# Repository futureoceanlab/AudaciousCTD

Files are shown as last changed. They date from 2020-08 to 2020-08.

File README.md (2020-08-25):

# AudaciousCTD

To understand any phenomenon about the ocean, we need to understand its basic
physical properties. Conductivity, tempreature and pressure are  
common data to be collected to estimate the local salinity of seawater at
certain depths. They are measured by using a sensor referred to as a 
conductivity, temperature and depth (CTD) sensor. It turns out that the existing
technologies are extremely costly due to their precision and depth ratings 
(a list of quates from various companies are available in 
**Markeg_Survey.xlsx**). For some scientific studies, the precision and depth 
rating specifications from these manufacturers are important. However, 
their high cost prevent us from understanding beyond local phenomenon in 
the ocean. 

Ocean is dynamic from molecular to global physical scales. Therefore, it is not
sufficient to operate with a few great CTDs. If their cost of a CTD could be 
lowered, we could have a more detailed understanding of the ocean. Furthermore,
the entry barrier for people to help study the ocean would be lowered 
significantly. We hope to acheive that via Audacious CTD project.

## Software

This was the last version of the MCU code used for the first iteration of the
Audacious CTD. It has not been maintained since June 2019.

The MCU used in this iteration was a STM32F303. 

The role of the MCU is very simple. Every given period, it will sample
the conductivity, temperature and pressure data from its sensors. Then, it will
save them to the flash memory. 

To edit the code, we recommend the use of STM32 Cube IDE. To program
the MCU, we recommend the use of STM32CubeProgrammer. This software also
enables the user to directly import the data that have been written to the 
flash drive. We took this approach in the first iteration.

## Circuit
The latest version of the circuit has been added to this repository. There
are two separte parts. One part has an MCU and its peripherals, and another
part has sensor-related components. The MCU component was housed inside, and
the sensor component was potted in the endcap to expose the sensors to the
seawater. 

At the point of fabrication, we thought having two separate board layouts (one 
for inside the housing and another for exposed circuit with sensors) on one 
board would save cost. However, it only caused confusion on the manufacturing 
company, and we would highly advise simply making two separte boards.

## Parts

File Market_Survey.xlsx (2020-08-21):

Supplier | Item | Conductivity (mS/cm) |  |  | Temperature (°C) |  |  | Depth (m) |  |  | Price | Link
 |  | Range | Accuracy | Resolution | Range | Accuracy | Resolution | Range | Accuracy | Resolution
STAR:ODDI | DST CTD Online | 13 to 63 | ±2 | 0.02 | -1 to 40 | ±0.1 | 0.032 |  | ±0.6% | 0.03% | $2980.00 | https://www.star-oddi.com/products/submersible-water-sensors/conductivity-salinity-sensor
 |  | 13 to 50 | ±1.5 | 0.01 | -1 to 41 | ±0.1 | 0.032 |  | ±0.6% | 100.03%
 |  | 3 to 37 | ±1.5 | 0.01 | -1 to 42 | ±0.1 | 0.032 |  | ±0.6% | 200.03%
 |  | 0.3 to 5 | ±0.3 | 0.002 | -1 to 43 | ±0.1 | 0.032 |  | ±0.6% | 300.03%
AML | Base-X | 0 to 90 | ±0.01 | ±0.003 | -5 to 45 | ±0.005 | ±0.003 | 500 | ±0.05% FS | 0.03%FS | $7225.00 | https://amloceanographic.com/product/base-x/#sound-velocity
 | Minos-X | 0 to 90 | ±0.01 | ±0.003 | -5 to 45 | ±0.005 | ±0.003 | 1000 | ±0.05% FS | 0.03%FS | $10085.00
Teledyne Marine | CT-EK Digital | 0 to 70 | ±0.1 | 0.0001 | -2 to 35 | ±0.05 | 0.0001 | 500 |  |  |  | http://www.teledynemarine.com/citadel-ct-ek-digital?ProductLineID=31
 | CT-EK Analog | 0 to 70 | ±0.01 | - | -2 to 35 | ±0.05 | - | 500 |  |  |  | http://www.teledynemarine.com/citadel-ctd-ek-analog?ProductLineID=31
 | CTD-ES | 0 to 70 | ±0.003 | 0.001 | -2 to 32 | ±0.002 | 0.0001 | 500 |  |  |  | http://www.teledynemarine.com/citadel-ctd-es?ProductLineID=31
OGI (Valeport) | miniCTD | 0 to 80 | ±0.01 | 0.001 | -5 to 35 | ±0.01 | 0.001 |  |  |  |  | http://www.valeport.co.uk/Portals/0/Docs/Datasheets/Valeport-miniCT.pdf
Idronaut | OS307 | 0 to 90 | ±0.003 | 0.0003 | -5 to 40 | ±0.003 | 0.001 | 0 to 1000 | 0.01% | 0.001% | EUR 4800 | https://www.idronaut.it/sensors/os307-oem-modules/#1560333614808-f7202d5a-61f3
 |  | 0 to 90 | ±0.003 | 0.0003 | -5 to 40 | ±0.003 | 0.001 | No Depth Sensor |  |  | EUR 4000
OpenCTD |  | 0.005 to 200 | ±2% | 0.001 | -55 to 125 | ±0.5 |  | 300 |  |  | $400.00 | https://github.com/OceanographyforEveryone/OpenCTD
OTT HydroMat | OTT CTD Sensor | 0.1 to 100 | ±1.5% | 0.01 | -25 to 70 | ±0.1 | 0.01 | 100 |  |  | - | https://www.ott.com/products/water-level-1/ott-ctd-sensor-37/
 | HL4 | 0 to 100 | ±0.5%+0.001 | 0.001 |  |  |  |  |  |  |  | https://www.ott.com/products/water-quality-2/hydrolab-hl4-multiparameter-sonde-54/
MeterGroup | ES-2 | 0 to 120 | ±10% or ±0.01 | 0.001 | -11 to 49 | ±1 | 0.1 | No Depth Sensor |  |  | $198.00 | https://www.metergroup.com/crops/products/es-2-electrical-conductivity-temperature-sen/
 | Hydros-21 | 0 to 120 | ±10% or ±0.01 | 0.001 | -11 to 49 | ±1 | 0.1 | 10 | ±0.5% |  |  | https://www.metergroup.com/environment/products/hydros-21-water-level-monitoring/
RBR | CTD | 0 to 85 | ±0.003 | 0.001 | -5 to 35 | ±0.002 | <0.00005 | 750 | ±0.05% | ±0.001% | $7320.00 | https://rbr-global.com/products/standard-loggers/rbrduo-ct
Seametrics | CT2X | 0 to 300 | ±0.5% | 0.001 | -5 to 40 | ±0.25 | 0.1 | 200 | 0.10% | 0.0034% FS | $2189.00 | https://www.seametrics.com/product/ct2x/
JFE AdvTech / Rockland Scientific | INFINITY-CT A7CT-USB | 0.5 to 70 | ±0.01 | 0.001 | 0 to 35 | ±0.01 | 0.001 | 200 | No Depth Sensor |  | $3200.00 | https://www.jfe-advantech.co.jp/eng/ocean/infinity/infinity-ct.html
 | INFINITY-CT A7CT2-USB | 0.5 to 70 | ±0.01 | 0.001 | 0 to 35 | ±0.01 | 0.001 | 2000 |  |  | $3830.00
 | DEFI2-CT |  | ±0.05 |  |  | ±0.05 |  | 200 |  |  | 2135+500
 | DEFI2-D |  |  |  |  |  |  | 500 | 0.30% | 0.05 | 1700+500
NKE Instrumentation | WiSens CTDS 50 | 0 to 70 | ±0.04 |  | -2 to 35 | ±0.005 |  | 50 | 0.15% |  | $3913.00 | https://nke-instrumentation.com/underwater-loggers/
 | WiSens CTDS 300 | 0 to 70 | ±0.04 |  | -2 to 35 | ±0.005 |  | 300 | 0.15% |  | $3913.00
SeaBird | SBE16v2CAT | 0 to 90 | ±0.0005 | 5e-05 | -5 to 35 | ±0.005 | 0.0001 |  | 0.1% FS | 0.002%FS | - | https://www.seabird.com/moored/sbe-16plus-v2-seacat-ct-d/family?productCategoryId=54627473773

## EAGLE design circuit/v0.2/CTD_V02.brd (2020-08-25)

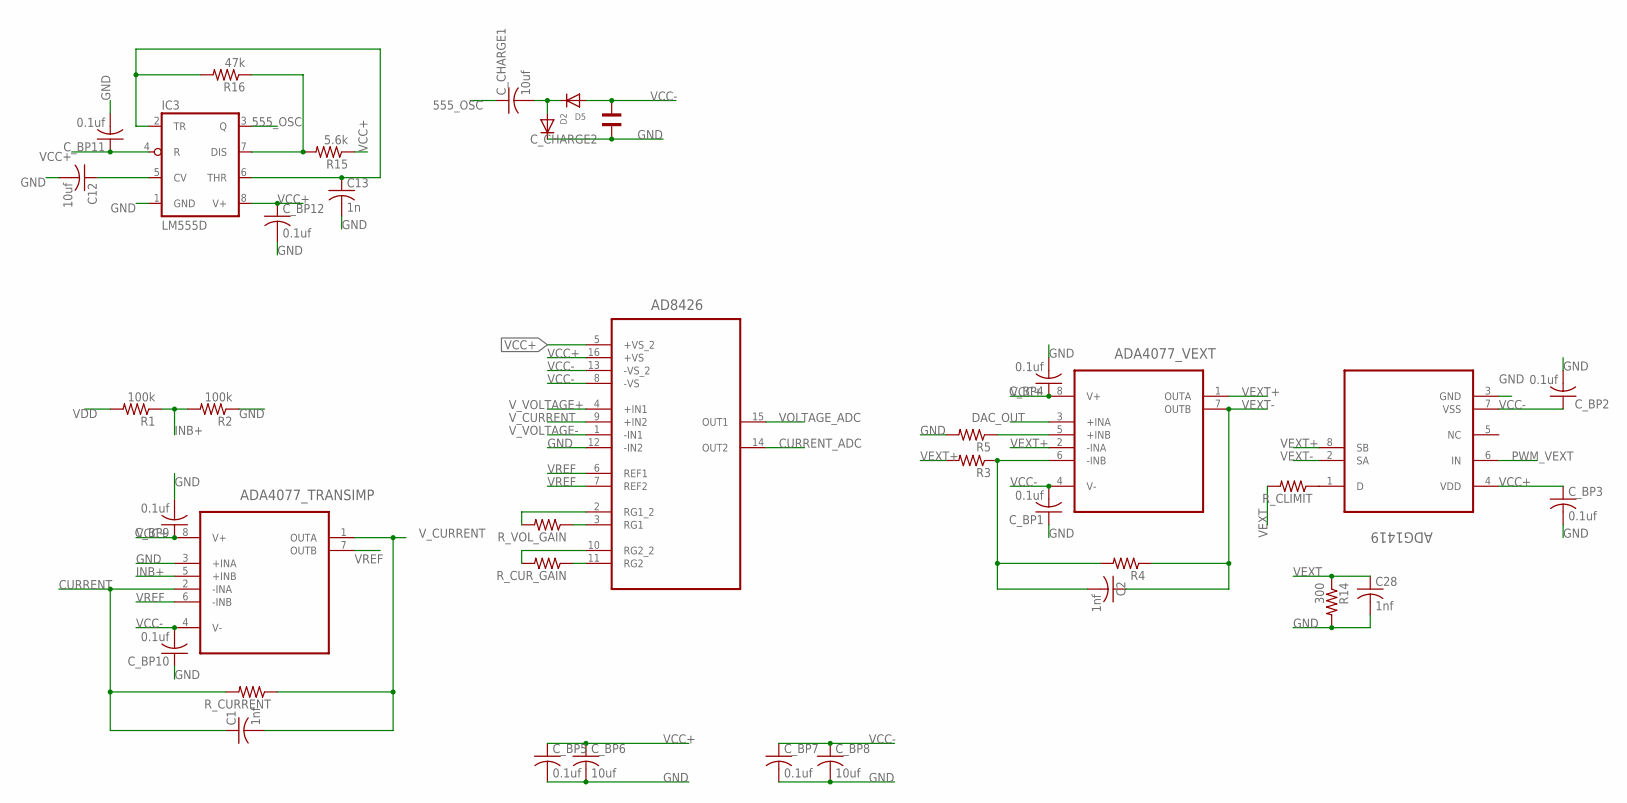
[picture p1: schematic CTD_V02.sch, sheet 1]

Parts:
AD8426: AD8426BCPZ-WP; QFN65P400X400X100-16N
ADA4077_TRANSIMP, ADA4077_VEXT: ADA4075-2ARZ; SOIC127P600X175-8N; MPN ADA4077
ADG1419: ADG1419BRMZ; SOP65P490X110-8N
C1, C2, C28: 1nf; C0603
C12: 10uf; C0603
C13: 1n; C0603
C_BP1, C_BP2, C_BP3, C_BP4, C_BP5, C_BP7, C_BP9, C_BP10, C_BP11, C_BP12: 0.1uf; C0603
C_BP6, C_BP8: 10uf; C0603
C_CHARGE1: 10uf; C0603
C_CHARGE2: WCAP-CSGP_1206_885012008001; WCAP-CSGP_1206
D2, D5: DIODESOD-123; SOD-123
IC3: LM555D; SO08
R1, R2: 100k; R0603
R3, R4, R5: R-US_R0603; R0603
R14: 300; R0603
R15: 5.6k; R0603
R16: 47k; R0603
R_CLIMIT: R-US_R0603; R0603
R_CURRENT: R-US_R0603; R0603
R_CUR_GAIN: R-US_R0603; R0603
R_VOL_GAIN: R-US_R0603; R0603

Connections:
555_OSC: C_CHARGE1.1, IC3.3 (Q)
CURRENT: ADA4077_TRANSIMP.2 (-INA), C1.1, R_CURRENT.2; also elsewhere on the board
CURRENT_ADC: AD8426.14 (OUT2); also elsewhere on the board
DAC_OUT: ADA4077_VEXT.3 (+INA); also elsewhere on the board
GND: AD8426.12 (-IN2), ADA4077_TRANSIMP.3 (+INA), ADG1419.3 (GND), C12.2, C13.2, C28.2, C_BP1.1, C_BP2.2, C_BP3.2, C_BP4.2, C_BP5.2, C_BP6.2, C_BP7.2, C_BP8.2, C_BP9.2, C_BP10.1, C_BP11.2, C_BP12.2, C_CHARGE2.2, D2.C, IC3.1 (GND), R2.1, R5.2, R14.2; also elsewhere on the board
INB+: ADA4077_TRANSIMP.5 (+INB), R1.1, R2.2
unnamed: AD8426.2 (RG1_2), R_VOL_GAIN.2
unnamed: AD8426.3 (RG1), R_VOL_GAIN.1
unnamed: AD8426.10 (RG2_2), R_CUR_GAIN.2
unnamed: ADA4077_VEXT.5 (+INB), R5.1
unnamed: AD8426.11 (RG2), R_CUR_GAIN.1
unnamed: ADA4077_VEXT.6 (-INB), C2.2, R3.1, R4.2
unnamed: IC3.7 (DIS), R15.2, R16.1
unnamed: C12.1, IC3.5 (CV)
unnamed: ADG1419.1 (D), R_CLIMIT.1
unnamed: C_CHARGE1.2, D2.A, D5.C
unnamed: C13.1, IC3.2 (TR), IC3.6 (THR), R16.2
PWM_VEXT: ADG1419.6 (IN); also elsewhere on the board
VCC+: AD8426.5 (+VS_2), AD8426.16 (+VS), ADA4077_TRANSIMP.8 (V+), ADA4077_VEXT.8 (V+), ADG1419.4 (VDD), C_BP3.1, C_BP4.1, C_BP5.1, C_BP6.1, C_BP9.1, C_BP11.1, C_BP12.1, IC3.4 (R), IC3.8 (V+), R15.1; also elsewhere on the board
VCC-: AD8426.8 (-VS), AD8426.13 (-VS_2), ADA4077_TRANSIMP.4 (V-), ADA4077_VEXT.4 (V-), ADG1419.7 (VSS), C_BP1.2, C_BP2.1, C_BP7.1, C_BP8.1, C_BP10.2, C_CHARGE2.1, D5.A
VDD: R1.2; also elsewhere on the board
VEXT: C28.1, R14.1, R_CLIMIT.2; also elsewhere on the board
VEXT+: ADA4077_VEXT.1 (OUTA), ADA4077_VEXT.2 (-INA), ADG1419.8 (SB), R3.2
VEXT-: ADA4077_VEXT.7 (OUTB), ADG1419.2 (SA), C2.1, R4.1
VOLTAGE_ADC: AD8426.15 (OUT1); also elsewhere on the board
VREF: AD8426.6 (REF1), AD8426.7 (REF2), ADA4077_TRANSIMP.6 (-INB), ADA4077_TRANSIMP.7 (OUTB)
V_CURRENT: AD8426.9 (+IN2), ADA4077_TRANSIMP.1 (OUTA), C1.2, R_CURRENT.1
V_VOLTAGE+: AD8426.4 (+IN1); also elsewhere on the board
V_VOLTAGE-: AD8426.1 (-IN1); also elsewhere on the board

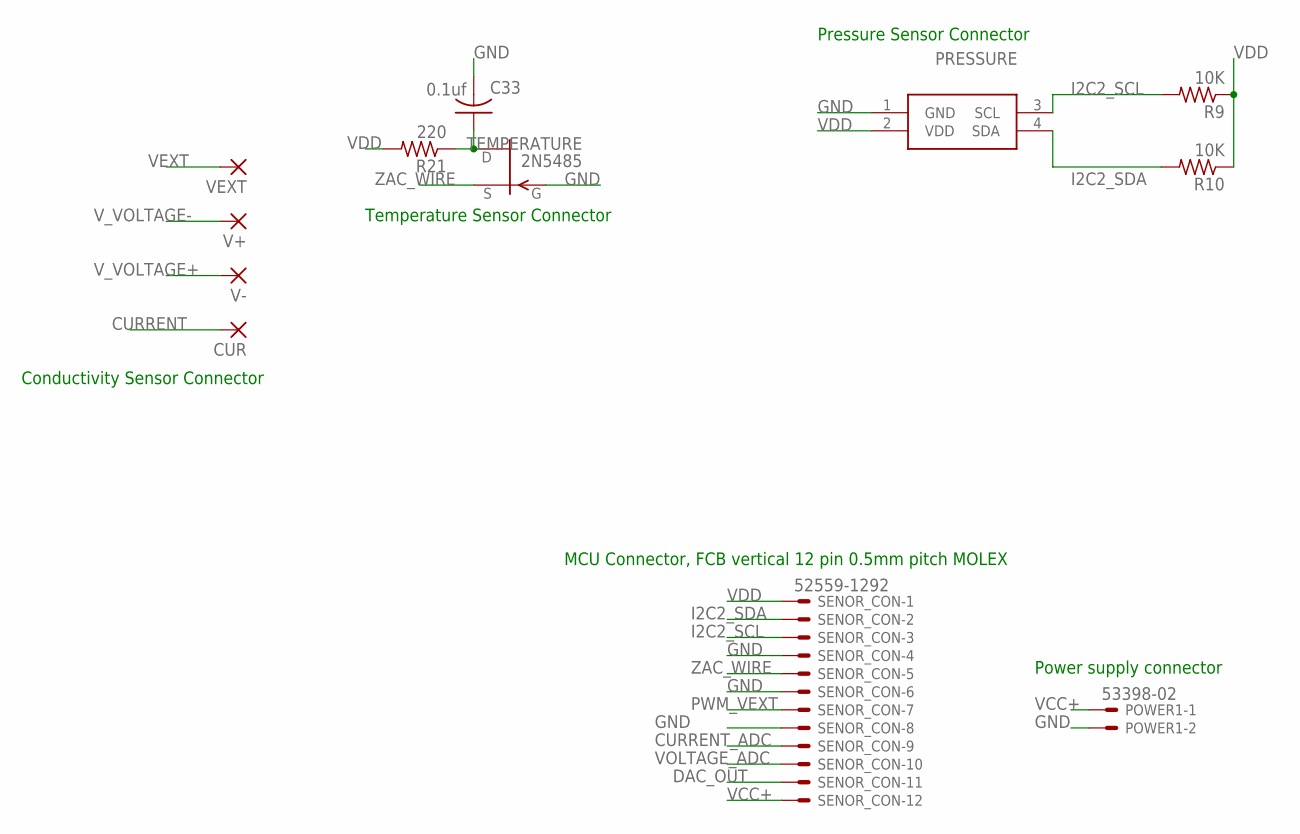
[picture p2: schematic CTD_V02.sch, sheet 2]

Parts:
C33: 0.1uf; C0603
CUR: SMD2; SMD1,27-2,54
POWER1: 53398-02
PRESSURE: MS583702BA01-50; MS583702BA0150
R9, R10: 10K; R0603
R21: 220; R0603
SENOR_CON: 52559-1292
TEMPERATURE: 2N5485; TO92-
V+: SMD2; SMD1,27-2,54
V-: SMD2; SMD1,27-2,54
VEXT: SMD2; SMD1,27-2,54

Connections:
CURRENT: CUR.1; also elsewhere on the board
CURRENT_ADC: SENOR_CON.9; also elsewhere on the board
DAC_OUT: SENOR_CON.11; also elsewhere on the board
GND: C33.2, POWER1.2, PRESSURE.1 (GND), SENOR_CON.4, SENOR_CON.6, SENOR_CON.8, TEMPERATURE.1 (G); also elsewhere on the board
I2C2_SCL: PRESSURE.3 (SCL), R9.2, SENOR_CON.3
I2C2_SDA: PRESSURE.4 (SDA), R10.2, SENOR_CON.2
unnamed: C33.1, R21.1, TEMPERATURE.3 (D)
PWM_VEXT: SENOR_CON.7; also elsewhere on the board
VCC+: POWER1.1, SENOR_CON.12; also elsewhere on the board
VDD: PRESSURE.2 (VDD), R9.1, R10.1, R21.2, SENOR_CON.1; also elsewhere on the board
VEXT: VEXT.1; also elsewhere on the board
VOLTAGE_ADC: SENOR_CON.10; also elsewhere on the board
V_VOLTAGE+: V-.1; also elsewhere on the board
V_VOLTAGE-: V+.1; also elsewhere on the board
ZAC_WIRE: SENOR_CON.5, TEMPERATURE.2 (S)

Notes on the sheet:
MCU Connector, FCB vertical 12 pin 0.5mm pitch MOLEX
Power supply connector
Conductivity Sensor Connector
Temperature Sensor Connector
Pressure Sensor Connector

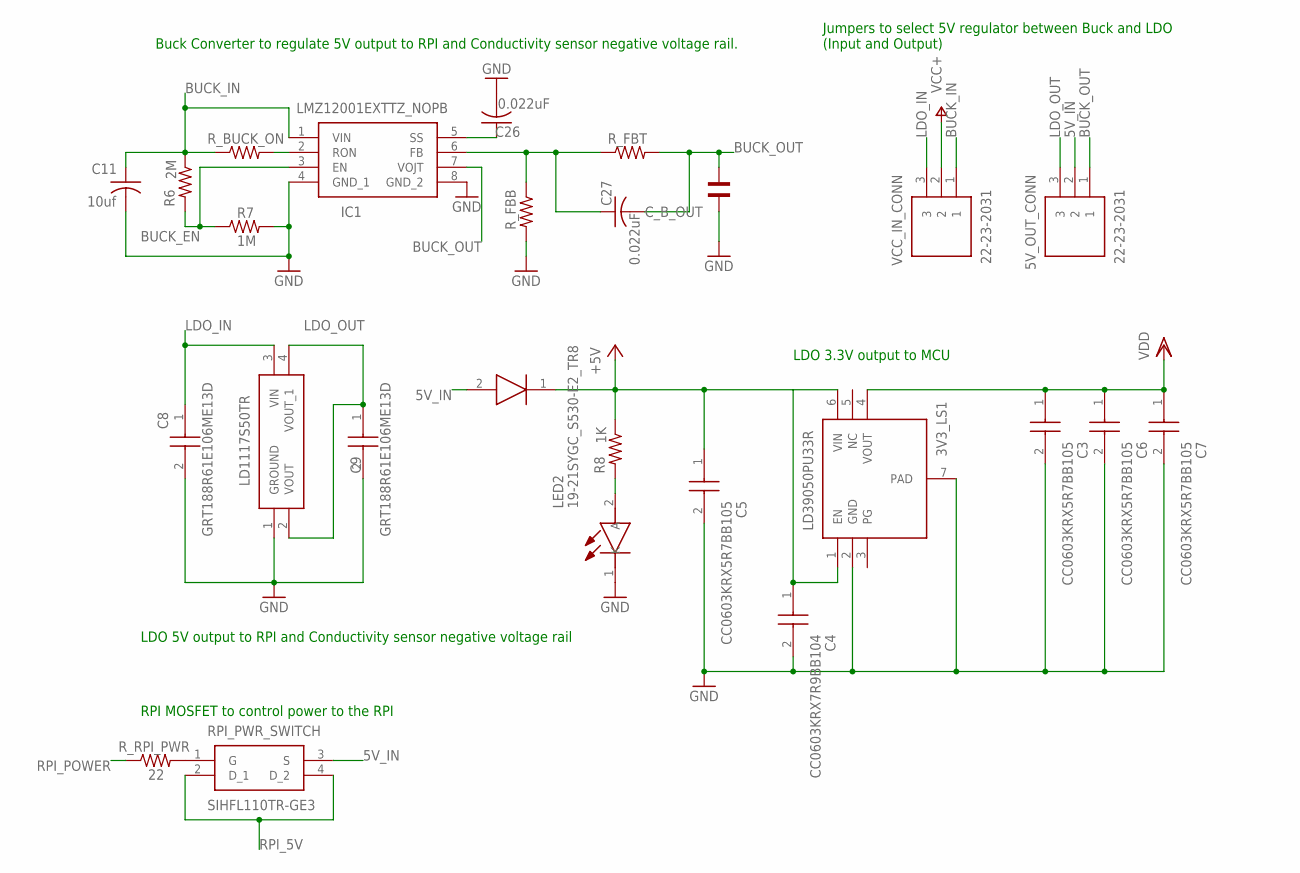
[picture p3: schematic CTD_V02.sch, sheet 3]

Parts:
3V3_LS1: LD39050PU33R; SON95P300X300X100-7N
5V_LS1: LD1117S50TR; SOT230P700X190-4N
5V_OUT_CONN: 22-23-2031; SHDR3W87P0X254_1X3_747X635X843
C3, C5, C6, C7: CC0603KRX5R7BB105; CAPC1608X90N
C4: CC0603KRX7R9BB104; CAPC1608X90N
C8, C9: GRT188R61E106ME13D; CAPC1608X100N
C11: 10uf; C0603
C26, C27: 0.022uF; C0603
C_B_OUT: WCAP-CSGP_1206_885012008001; WCAP-CSGP_1206
D3: STPS2L30A; DIOM5126X265N
IC1: LMZ12001EXTTZ_NOPB; NDW0007A
LED2: 19-21SYGC_S530-E2_TR8; LEDC1608X90N
R6: 2M; R0603
R7: 1M; R0603
R8: 1K; R0603
RPI_PWR_SWITCH: SIHFL110TR-GE3; SOT230P700X180-4N
R_BUCK_ON: R-US_R0603; R0603
R_FBB: R-US_R0603; R0603
R_FBT: R-US_R0603; R0603
R_RPI_PWR: 22; R0603
VCC_IN_CONN: 22-23-2031; SHDR3W87P0X254_1X3_747X635X843

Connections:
5V_IN: 5V_OUT_CONN.2, D3.2 (A), RPI_PWR_SWITCH.3 (S); also elsewhere on the board
+5V: 3V3_LS1.1 (EN), 3V3_LS1.6 (VIN), C4.1, C5.1, D3.1 (K), R8.1
BUCK_EN: IC1.3 (EN), R6.2, R7.1
BUCK_IN: C11.1, IC1.1 (VIN), R6.1, R_BUCK_ON.1, VCC_IN_CONN.1
BUCK_OUT: 5V_OUT_CONN.1, C27.2, C_B_OUT.1, IC1.7 (VOJT), R_FBT.2
GND: 3V3_LS1.2 (GND), 3V3_LS1.7 (PAD), 5V_LS1.1 (GROUND), C3.2, C4.2, C5.2, C6.2, C7.2, C8.2, C9.2, C11.2, C26.2, C_B_OUT.2, IC1.4 (GND_1), IC1.8 (GND_2), LED2.1 (K), R7.2, R_FBB.2; also elsewhere on the board
LDO_IN: 5V_LS1.3 (VIN), C8.1, VCC_IN_CONN.3
LDO_OUT: 5V_LS1.2 (VOUT), 5V_LS1.4 (VOUT_1), 5V_OUT_CONN.3, C9.1
unnamed: C27.1, IC1.6 (FB), R_FBB.1, R_FBT.1
unnamed: C26.1, IC1.5 (SS)
unnamed: IC1.2 (RON), R_BUCK_ON.2
unnamed: LED2.2 (A), R8.2
unnamed: RPI_PWR_SWITCH.1 (G), R_RPI_PWR.2
RPI_5V: RPI_PWR_SWITCH.2 (D_1), RPI_PWR_SWITCH.4 (D_2); also elsewhere on the board
RPI_POWER: R_RPI_PWR.1; also elsewhere on the board
VCC+: VCC_IN_CONN.2; also elsewhere on the board
VDD: 3V3_LS1.4 (VOUT), C3.1, C6.1, C7.1; also elsewhere on the board

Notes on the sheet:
Buck Converter to regulate 5V output to RPI and Conductivity sensor negative voltage rail.
LDO 5V output to RPI and Conductivity sensor negative voltage rail
LDO 3.3V output to MCU
Jumpers to select 5V regulator between Buck and LDO (Input and Output)
RPI MOSFET to control power to the RPI

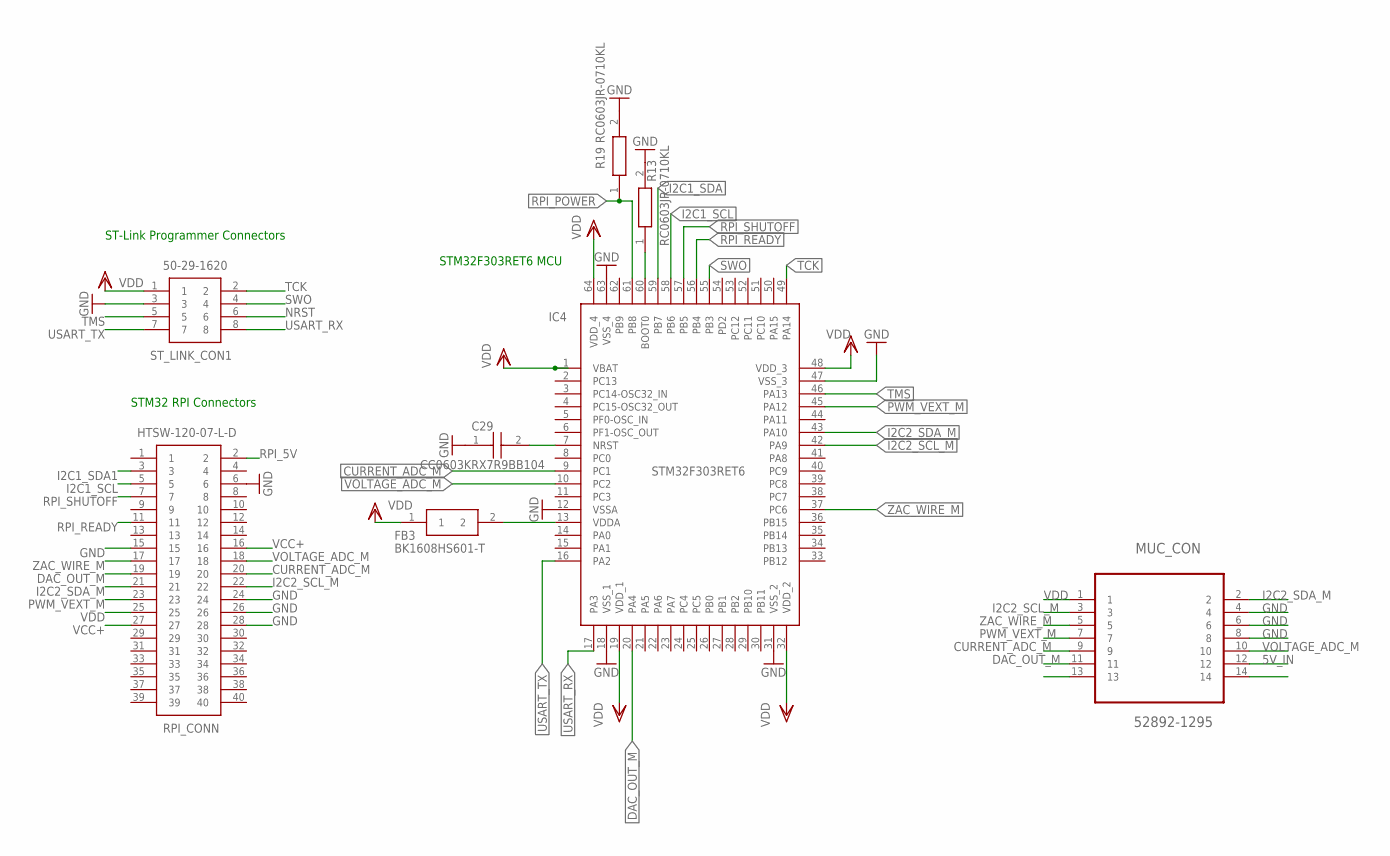
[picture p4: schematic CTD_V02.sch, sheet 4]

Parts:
C29: CC0603KRX7R9BB104; CAPC1608X90N
FB3: BK1608HS601-T; BEADC1608X95N
IC4: STM32F303RET6; QFP50P1200X1200X160-64N
MUC_CON: 52892-1295; MOLEX_52892-1295
R13, R19: RC0603JR-0710KL; RESC1608X55N
RPI_CONN: HTSW-120-07-L-D; SAMTEC_HTSW-120-07-L
ST_LINK_CON1: 50-29-1620; 50291620

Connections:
5V_IN: MUC_CON.12; also elsewhere on the board
CURRENT_ADC_M: IC4.9 (PC1), MUC_CON.9, RPI_CONN.20
DAC_OUT_M: IC4.20 (PA4), MUC_CON.11, RPI_CONN.19
GND: C29.1, IC4.12 (VSSA), IC4.18 (VSS_1), IC4.31 (VSS_2), IC4.47 (VSS_3), IC4.63 (VSS_4), MUC_CON.4, MUC_CON.6, MUC_CON.8, R13.2, R19.2, RPI_CONN.6, RPI_CONN.15, RPI_CONN.24, RPI_CONN.26, RPI_CONN.28, ST_LINK_CON1.3; also elsewhere on the board
I2C1_SCL: IC4.58 (PB6), RPI_CONN.5
I2C1_SDA: IC4.59 (PB7)
I2C1_SDA1: RPI_CONN.3
I2C2_SCL_M: IC4.42 (PA9), MUC_CON.3, RPI_CONN.22
I2C2_SDA_M: IC4.43 (PA10), MUC_CON.2, RPI_CONN.21
unnamed: IC4.60 (BOOT0), R13.1
unnamed: FB3.2, IC4.13 (VDDA)
NRST: C29.2, IC4.7 (NRST), ST_LINK_CON1.6
PWM_VEXT_M: IC4.45 (PA12), MUC_CON.7, RPI_CONN.23
RPI_5V: RPI_CONN.2; also elsewhere on the board
RPI_POWER: IC4.61 (PB8), R19.1; also elsewhere on the board
RPI_READY: IC4.56 (PB4), RPI_CONN.11
RPI_SHUTOFF: IC4.57 (PB5), RPI_CONN.7
SWO: IC4.55 (PB3), ST_LINK_CON1.4
TCK: IC4.49 (PA14), ST_LINK_CON1.2
TMS: IC4.46 (PA13), ST_LINK_CON1.5
USART_RX: IC4.17 (PA3), ST_LINK_CON1.8
USART_TX: IC4.16 (PA2), ST_LINK_CON1.7
VCC+: RPI_CONN.16, RPI_CONN.27; also elsewhere on the board
VDD: FB3.1, IC4.1 (VBAT), IC4.19 (VDD_1), IC4.32 (VDD_2), IC4.48 (VDD_3), IC4.64 (VDD_4), MUC_CON.1, RPI_CONN.25, ST_LINK_CON1.1; also elsewhere on the board
VOLTAGE_ADC_M: IC4.10 (PC2), MUC_CON.10, RPI_CONN.18
ZAC_WIRE_M: IC4.37 (PC6), MUC_CON.5, RPI_CONN.17

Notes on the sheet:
ST-Link Programmer Connectors
STM32F303RET6 MCU
STM32 RPI Connectors

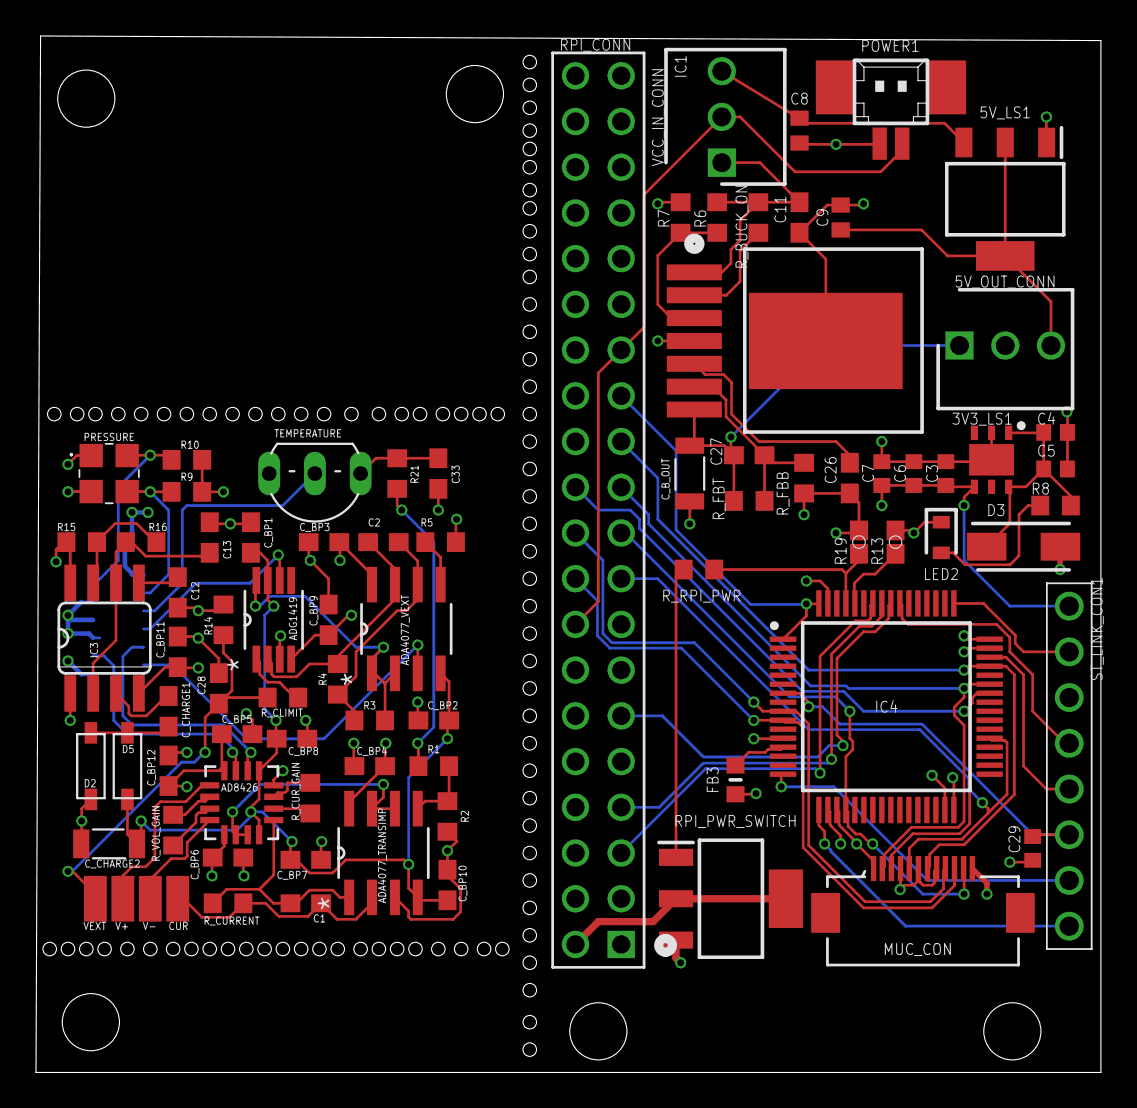
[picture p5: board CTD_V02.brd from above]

Board: 4 copper layers, 59.2 x 57.6 mm, 84 parts (1 on the bottom side), 65 nets.

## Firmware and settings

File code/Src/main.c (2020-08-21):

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

/* Includes ------------------------------------------------------------------*/
#include "main.h"

/* USER CODE BEGIN Includes */
#include "string.h"

#include "analogue.h"
#include "UART.h"
#include "timer.h"
#include "I2C.h"
#include "conductivity.h"
#include "temperature.h"
#include "pressure.h"
#include "flash.h"
#include "RPI.h"
#include "GPIO.h"

/* USER CODE END Includes */


/* USER CODE BEGIN PD */
#define MAX_FLASH_PAGE_SIZE FLASH_PAGE_SIZE


void Peripheral_Init(void);
void SystemClock_Config(void);
void MX_GPIO_Init(void);
void Measure_Data(struct SensorData *s_data);
uint8_t Find_Start_End_Page(uint8_t *start_page, uint8_t *end_page);

uint8_t Check_System(void);
uint8_t Check_Data(void);

uint32_t global_idx, cur_addr, ts = 0;
uint8_t cur_page, unlogged_start_page;
uint16_t nth_page;
uint16_t s_data_array_len = 0;


/**
  * @brief  The application entry point.
  * @retval int
  */
int main(void)
{
	Peripheral_Init();
	HAL_GPIO_WritePin(GPIOB, RPI_Pwr_Enable_Pin, GPIO_PIN_SET);
//	RPI_Off();
	char *m ="Check Sys\r\n";
	HAL_UART_Transmit(&huart2, (uint8_t*)m, strlen(m), 1000);

	/* System Check Start-------------------------------------------------------- */
	int8_t sys_success = Check_System();

	char mm[100];
	sprintf(mm, "success = %u\r\n", sys_success);
	HAL_UART_Transmit(&huart2, (uint8_t*)m, strlen(m), 1000);

	if (sys_success) {
		HAL_GPIO_WritePin(SYS_STATUS_GPIO_Port, SYS_STATUS_Pin, SET);
		m ="Sys Check Sucecssful\r\n";
		HAL_UART_Transmit(&huart2, (uint8_t*)mm, strlen(mm), 1000);
	} else {
	// Failed
		while (1) {
			HAL_GPIO_TogglePin(SYS_STATUS_GPIO_Port, SYS_STATUS_Pin);
			HAL_Delay(500);
		}
	}
//
//	/* Check if we are in the water or in the air ------------------------------ */
////	uint8_t in_water = Conductivity_check();
////	if (!in_water) {
////		RPI_Wifi(&ts);
////	}
////	while (!Conductivity_cConductivity_Measure_Singleheck()) {}
//	RPI_Off();

	/* Measurement Start-------------------------------------------------------- */
	if (HAL_TIM_Base_Start_IT(&htim2) != HAL_OK) Error_Handler();
	while (1)
	{
	}
}

void Peripheral_Init(void) {
	/* MCU Configuration----------------------------------------------------------*/
	/* Reset of all peripherals, Initializes the Flash interface and the Systick. */
	HAL_Init();
	/* Configure the system clock */
	SystemClock_Config();
	/* Initialize all configured peripherals */
	MX_GPIO_Init();
	MX_ADC1_Init();
	MX_ADC2_Init();
	MX_DAC1_Init();
	MX_I2C1_Init();
	MX_I2C2_Init();
	MX_TIM2_Init();
	MX_TIM3_Init();
	MX_TIM4_Init();
	MX_USART2_UART_Init();
//	HAL_InitTick(12);
}


void HAL_TIM_PeriodElapsedCallback(TIM_HandleTypeDef *htim)
{
// Conductivity Measurement Interrupt
	if(TIM4 == htim->Instance) {
		// Sampling High and Low, Sample size needs plus one and double
		// If done sampling, stop tim4 interrupts and DAC
		if (sample_num < (SAMPLE_SIZE +1) *2){
				Conductivity_Measure_Single();
		}
		else{
			HAL_TIM_Base_Stop(&htim4);
			HAL_GPIO_WritePin(GPIOA, GPIO_PIN_12, 0);
		}
	} else if (TIM2 == htim->Instance) {
//		HAL_GPIO_TogglePin(SYS_STATUS_GPIO_Port, SYS_STATUS_Pin);
//		if (cur_page < 2) {
		ts++;
		global_idx++;
		char *m = "+";
		HAL_UART_Transmit(&huart2, (uint8_t*)m, strlen(m), 1000);

		struct SensorData s_data;
		Measure_Data(&s_data);
		s_data_array[s_data_array_len] = s_data;
		s_data_array_len++;

		if (s_data_array_len == MAX_SENSOR_DATA_ARR_LEN) {
			int8_t log_successful = -1;
			Flash_Save_Bulk_Data(&s_data_array, s_data_array_len, cur_page, nth_page);
//			if ((RPI_Status == RPI_OFF)
//					&& ((((int8_t)(cur_page - unlogged_start_page)) % 5) == 4)) {
//				// Try to save to RPI every multiple of 5 pages, so turn it on
//				RPI_On();
//			}
//			if (RPI_Status == RPI_ON) {
//				m = "Store at RPI\r\n";
//				HAL_UART_Transmit(&huart2, (uint8_t*)m, strlen(m), 1000);
//				if ((log_successful = RPI_Log_Bulk_Data(unlogged_start_page, cur_page, &ts)) != -1) {
//					unlogged_start_page = cur_page;
//					RPI_Off();
//				}
//			}
			cur_page = (cur_page + 1) % FLASH_TOTAL_DATA_PAGES;
//			if (Flash_Get_Nth_Page(cur_page) != 0xFFFF) {
//				// Reached the first page that needs to be logged
//				// Flash is full, so keep trying to save to RPI
//				// Pause any measurement until then
//				if (RPI_Status == RPI_OFF) RPI_On();
//				if (HAL_TIM_Base_Stop_IT(&htim2) != HAL_OK) Error_Handler();
//				if (HAL_TIM_Base_Stop_IT(&htim4) != HAL_OK) Error_Handler();
//				// Wait until RPI is fully on!
//				while (RPI_Status != RPI_ON) {}
//				// Keep trying to save the file until the end...!
//				while (log_successful == -1) {
//					log_successful = RPI_Log_Bulk_Data(unlogged_start_page, cur_page, &ts);
//				}
//
//				// Restart measuring!
//				if (HAL_TIM_Base_Start_IT(&htim2) != HAL_OK) Error_Handler();
//				if (HAL_TIM_Base_Start_IT(&htim4) != HAL_OK) Error_Handler();
//			}
			nth_page ++;
			s_data_array_len = 0;
			char mm[100];
			sprintf(mm, "len=%u, moved to new page %u\r\n", MAX_SENSOR_DATA_ARR_LEN, cur_page);
			HAL_UART_Transmit(&huart2, (uint8_t*)mm, strlen(mm), 1000);
		}
		/* Upload Done */
//		}
		/* Request to enter SLEEP mode */
//		HAL_PWR_EnterSLEEPMode(PWR_MAINREGULATOR_ON, PWR_SLEEPENTRY_WFI);
	} else if(TIM3 == htim->Instance) {
//		Temperature_Measure(htim);
	}
}


void SystemClock_Config(void)
{
  RCC_OscInitTypeDef RCC_OscInitStruct = {0};
  RCC_ClkInitTypeDef RCC_ClkInitStruct = {0};
  RCC_PeriphCLKInitTypeDef PeriphClkInit = {0};

  /** Initializes the CPU, AHB and APB busses clocks
  */
  RCC_OscInitStruct.OscillatorType = RCC_OSCILLATORTYPE_HSI;
  RCC_OscInitStruct.HSIState = RCC_HSI_ON;
  RCC_OscInitStruct.HSICalibrationValue = RCC_HSICALIBRATION_DEFAULT;
  RCC_OscInitStruct.PLL.PLLState = RCC_PLL_ON;
  RCC_OscInitStruct.PLL.PLLSource = RCC_PLLSOURCE_HSI;
  RCC_OscInitStruct.PLL.PLLMUL = RCC_PLL_MUL2;
  RCC_OscInitStruct.PLL.PREDIV = RCC_PREDIV_DIV1;
  if (HAL_RCC_OscConfig(&RCC_OscInitStruct) != HAL_OK)
  {
    Error_Handler();
  }
  /** Initializes the CPU, AHB and APB busses clocks
  */
  RCC_ClkInitStruct.ClockType = RCC_CLOCKTYPE_HCLK|RCC_CLOCKTYPE_SYSCLK
                              |RCC_CLOCKTYPE_PCLK1|RCC_CLOCKTYPE_PCLK2;
  RCC_ClkInitStruct.SYSCLKSource = RCC_SYSCLKSOURCE_HSI;
  RCC_ClkInitStruct.AHBCLKDivider = RCC_SYSCLK_DIV1;
  RCC_ClkInitStruct.APB1CLKDivider = RCC_HCLK_DIV1;
  RCC_ClkInitStruct.APB2CLKDivider = RCC_HCLK_DIV1;

  if (HAL_RCC_ClockConfig(&RCC_ClkInitStruct, FLASH_LATENCY_0) != HAL_OK)
  {
    Error_Handler();
  }
  PeriphClkInit.PeriphClockSelection = RCC_PERIPHCLK_USART2|RCC_PERIPHCLK_ADC12
                              |RCC_PERIPHCLK_TIM34;
  PeriphClkInit.Usart2ClockSelection = RCC_USART2CLKSOURCE_PCLK1;
  PeriphClkInit.Adc12ClockSelection = RCC_ADC12PLLCLK_DIV1;
  PeriphClkInit.Tim34ClockSelection = RCC_TIM34CLK_HCLK;
  if (HAL_RCCEx_PeriphCLKConfig(&PeriphClkInit) != HAL_OK)
  {
    Error_Handler();
  }
}


uint8_t Check_Data(void) {
	uint8_t start_page = 0, end_page = 0;
	uint8_t new_flash = Find_Start_End_Page(&start_page, &end_page);
	nth_page = Flash_Get_Nth_Page(end_page);
	if (nth_page == 0xFFFF) nth_page = 0;
	char m[100];
	sprintf(m, "unlogged_start=%u, unlogged_end=%u, nth_page = %X\r\n",
			start_page, end_page, nth_page);
	HAL_UART_Transmit(&huart2, (uint8_t*)m, strlen(m), 1000);
	/* RPI Check and flash configuration */
//	RPI_On();
	if (new_flash) {
	// The sensor is brand new
		HAL_UART_Transmit(&huart2, (uint8_t*)m, strlen(m), 1000);

		cur_page = 0;
		unlogged_start_page = 0;
		nth_page = 1;
	} else {
	// Unlogged pages exist, save all the unsaved files to RPI
//		while ((cur_page + 1) %FLASH_TOTAL_DATA_PAGES == unlogged_start_page) {};
		unlogged_start_page = start_page;
		cur_page = (end_page + 1) % FLASH_TOTAL_DATA_PAGES;
		nth_page += 1;
//		char m[100];
//		sprintf(m, "cur_page=%u end_page=%u, nth_page=%u\r\n", cur_page, end_page, nth_page);
//		HAL_UART_Transmit(&huart2, (uint8_t*)m, strlen(m), 1000);
	}
//	while (RPI_Status != RPI_OFF) {};
	char *mm = "RPI is off now for real!!!!\r\n";
	HAL_UART_Transmit(&huart2, (uint8_t*)mm, strlen(m), 1000);
//	cur_page = 0;
//	unlogged_start_page = 0;
//	nth_page = 1;
	return 1;
}

uint8_t Find_Start_End_Page(uint8_t *start_page, uint8_t *end_page) {
	char m[100];
	nth_page = Flash_Get_Nth_Page(0);
	uint8_t page_x=0, page_y=0;
	sprintf(m, "INIT: nth_page = %u\r\n", nth_page);
	HAL_UART_Transmit(&huart2, (uint8_t*)m, strlen(m), 1000);

	if (nth_page != 0xFFFF) {
	// The first page has unlogged data. This could mean (1) 0-x pages are unlogged
	// or (2) 0-x and y-end pages are logged where y is the start and x is the end
	// (3) or 0-end pages are full...!
		char *mm = "Page is not new, search for a new page...\r\n";
		HAL_UART_Transmit(&huart2, (uint8_t*)mm, strlen(mm), 1000);

		while ((nth_page != 0xFFFF) && (page_x < FLASH_TOTAL_DATA_PAGES)) {
			page_x++;
			nth_page = Flash_Get_Nth_Page(page_x);
		}
		page_y = page_x;
		sprintf(m, "page_x = %u\r\n", page_x);
		HAL_UART_Transmit(&huart2, (uint8_t*)m, strlen(m), 1000);

		if (nth_page != 0xFFFF) {
			// case (3) 0-end unlogged pages
			// TODO: The order may actually not from 0 to end
			*start_page = 0;
			*end_page = FLASH_TOTAL_DATA_PAGES;
			mm = "case3: pages are all full and everything was unlogged\r\n";
			HAL_UART_Transmit(&huart2, (uint8_t*)mm, strlen(mm), 1000);
			return 0;
		} else {
			*end_page = page_x-1;
		}
		sprintf(m, "max = %u\r\n", FLASH_TOTAL_DATA_PAGES);
		HAL_UART_Transmit(&huart2, (uint8_t*)m, strlen(m), 1000);

		while ((nth_page == 0xFFFF) && (page_y < FLASH_TOTAL_DATA_PAGES)) {
			page_y++;
			nth_page = Flash_Get_Nth_Page(page_y);
		}
		sprintf(m, "page_y = %u, nth_page=%u\r\n", page_y, nth_page);
		HAL_UART_Transmit(&huart2, (uint8_t*)m, strlen(m), 1000);

		if (nth_page == 0xFFFF) {
			// case (1) 0-x unlogged pages
			*start_page = 0;
		} else {
			// case(2) 0-x and y-end unlogged pages
			*start_page = page_y;
		}
	} else {
	// The first page is untouched. This could mean (1) there is no data at all or
	// (2) x-y pages are unlogged
		while ((nth_page == 0xFFFF) && (page_x < FLASH_TOTAL_DATA_PAGES)) {
			page_x++;
			nth_page = Flash_Get_Nth_Page(end_page);
		}
		if (nth_page == 0xFFFF) {
		// case (1) no data
			*start_page = 0;
			*end_page = 0;
			return 1;
		} else {
			*start_page = page_x;
		}
		page_y = page_x;
		while ((nth_page != 0xFFFF) && (page_y < FLASH_TOTAL_DATA_PAGES)) {
			page_y++;
			nth_page = Flash_Get_Nth_Page(end_page);
		}
		*end_page = nth_page != 0xFFFF ? FLASH_TOTAL_DATA_PAGES: page_y - 1;
	}
	return 0;
}

uint8_t Check_System(void) {
	uint8_t sys_success = 0;
	/* Check the sensor validity-------------------------------------------------- */
	uint8_t sensor_success = 1;// Check_Sensors();
	uint8_t rpi_success = Check_Data();
	char *m = "Hello\r\n";
	HAL_UART_Transmit(&huart2, (uint8_t*)m, strlen(m), 1000);
	sys_success = (sensor_success << 1) +  rpi_success;
	HAL_UART_Transmit(&huart2, (uint8_t*)m, strlen(m), 1000);
	return sys_success;
}

void Measure_Data(struct SensorData *s_data) {
//	/* Measure conductivity */
	uint32_t c_data = Conductivity_Measure_Average();

//	/* Measure temperature */
//	Temperature_Enable();
//	while (!temperature_finished) {
//	// Wait until the temperature measurement is complete
//	}
	float t_data = Temperature_Measure(); //temperature;
	uint32_t t_int = (uint32_t)(t_data * 1000);
////	temperature_finished = 0;
////	Temperature_Disable();
//
//	/* Measure pressure */
	int32_t temp_T;
	uint32_t p_data;
//	float p_data = Pressure_Measure();
	Pressure_Measure(&p_data, &temp_T);
	uint32_t p_int = (uint32_t)(p_data*100);
	if (t_data > 80.f || t_data < 1.f) {
		t_int = (uint32_t) temp_T;
	}
	char m[100];
	int n = sprintf(m, "TS: %u, idx:%u C:%u\tT:%u.%u\tP:%u.%u\r\n",\
				ts, global_idx, c_data, (uint32_t)t_int/1000,\
			  ((uint32_t)(t_int))%1000, (uint32_t)p_int/1000, \
			  ((uint32_t)(p_int))%1000);
	HAL_UART_Transmit(&huart2, (uint8_t*)m, strlen(m), 1000);

//
//	/* Save the data to the flash */
//	// RTC ts, idx, start_addr, end_addr managing needed
//	// FLASH_USER_END_ADDR needs to be specified
	s_data->Idx = global_idx;
	s_data->Timestamp = ts;
	s_data->Conductivity = c_data;
	s_data->Temperature = t_int;
	s_data->Pressure =  p_int;
}


/**
  * @brief  This function is executed in case of error occurrence.
  * @retval None
  */
void Error_Handler(void)
{
  /* USER CODE BEGIN Error_Handler_Debug */
  /* User can add his own implementation to report the HAL error return state */

  /* USER CODE END Error_Handler_Debug */
}

#ifdef  USE_FULL_ASSERT
/**
  * @brief  Reports the name of the source file and the source line number
  *         where the assert_param error has occurred.
  * @param  file: pointer to the source file name
  * @param  line: assert_param error line source number
  * @retval None
  */
void assert_failed(char *file, uint32_t line)
{ 
  /* USER CODE BEGIN 6 */
  /* User can add his own implementation to report the file name and line number,
     tex: printf("Wrong parameters value: file %s on line %d\r\n", file, line) */
  /* USER CODE END 6 */
}
#endif /* USE_FULL_ASSERT */

/************************ (C) COPYRIGHT STMicroelectronics *****END OF FILE****/

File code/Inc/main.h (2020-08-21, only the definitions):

#define Current_ADC_Pin GPIO_PIN_1
#define Current_ADC_GPIO_Port GPIOC
#define Voltage_ADC_Pin GPIO_PIN_2
#define Voltage_ADC_GPIO_Port GPIOC
#define USART_TX_Pin GPIO_PIN_2
#define USART_TX_GPIO_Port GPIOA
#define USART_RX_Pin GPIO_PIN_3
#define USART_RX_GPIO_Port GPIOA
#define ZAC_Wire_Pin GPIO_PIN_6
#define ZAC_Wire_GPIO_Port GPIOC
#define PWM_Vext_Pin GPIO_PIN_12
#define PWM_Vext_GPIO_Port GPIOA
#define TMS_Pin GPIO_PIN_13
#define TMS_GPIO_Port GPIOA
#define TCK_Pin GPIO_PIN_14
#define TCK_GPIO_Port GPIOA
#define SYS_STATUS_Pin GPIO_PIN_3
#define SYS_STATUS_GPIO_Port GPIOB
#define RPI_Ready_Pin GPIO_PIN_4
#define RPI_Ready_GPIO_Port GPIOB
#define RPI_Shutdown_Pin GPIO_PIN_5
#define RPI_Shutdown_GPIO_Port GPIOB
#define RPI_Pwr_Enable_Pin GPIO_PIN_8
#define RPI_Pwr_Enable_GPIO_Port GPIOB

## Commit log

2020-08-21 add market survey
    [Market_Survey.xlsx]
2020-08-25 add circuit schematic and layout
    [CTD_V02.brd, CTD_V02.sch]
2020-08-25 add notes about the circuit

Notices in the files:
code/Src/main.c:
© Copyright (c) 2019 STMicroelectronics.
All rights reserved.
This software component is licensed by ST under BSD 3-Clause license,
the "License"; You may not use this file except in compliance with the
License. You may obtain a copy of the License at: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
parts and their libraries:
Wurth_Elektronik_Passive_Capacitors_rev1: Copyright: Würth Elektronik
